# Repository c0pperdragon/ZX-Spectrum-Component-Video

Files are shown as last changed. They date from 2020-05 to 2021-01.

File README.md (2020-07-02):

# ZX-Spectrum-Component-Video
Component video (YPbPr) output for the ZX Spectrum computer 

## General

The ZX Spectrum in its original form produces a radio frequency signal that can be fed into an analog TV. The quality of this
signal is very poor, but this can be improved by a simple modification that will make the ZX Spectrum output a composite video
signal instead. While this is actually better, it is nowhere near good. To bring the video quality to the next level,
this modification will produce a component video signal (YPbPr) that should be as good as an analog signal can possible get.
This video signal can be used either directly with a TV that has a YPbPr input, or it can be passed through a dedicated upscaler device
("Framemeister", "OSSC", etc.) before displaying on an HDMI screen.

This hardware modification is a more compact version of the solution that uses an A-Video board with seperate level shifters.
It tries to solve various shortcomings of https://github.com/c0pperdragon/A-VideoBoard/tree/master/zxspectrummod :

- Smaller and cheaper to make
- No need to modify the case of the ZX Spectrum
- No need to remove any components besides the RF modulator.

## Theory of operation

The mod board passively listens to various digital data lines through which the ULA communicates with the rest of the 
main board - specifically the signals CAS,RW,IOREQ and the data bus. This information is processed by the FPGA 
to figure out what image the ULA intends to display. The FPGA drives a simple 3-channel digital-to-analog converter built from
resistors to produce the 3 output voltages of the YPbPr signal.
Because the main board runs with 5 volt logic levels and the FPGA can only work with 3.3 volts, a voltage regulator and
two input level shifter ICs are necessary (on the bottom side of the mod board). 

## Video output possibilities

- 288p (default) or 576p
- YPbPr (default) or RGsB

Output modes can be selected by jumpers or optional switches.

The color palette I am using has slightly softened colors. The original monochromatic colors are just too hard on
my eyes especially when viewed on a modern display.
I took the platte from [https://lospec.com/palette-list/zx-spectrum] and in my opinion this really looks great.

## Drawbacks

Installation of the mod requires complete removal of the RF modulator. This also implies that an
existing composite video mod will no longer be available. Without further modification the 
ZX Spectrum will then work with component video output exclusively.

If you need composite video additionally you can wire up an extra connector, as the
original analog signals are still being produced by the video output circuit.

## Images
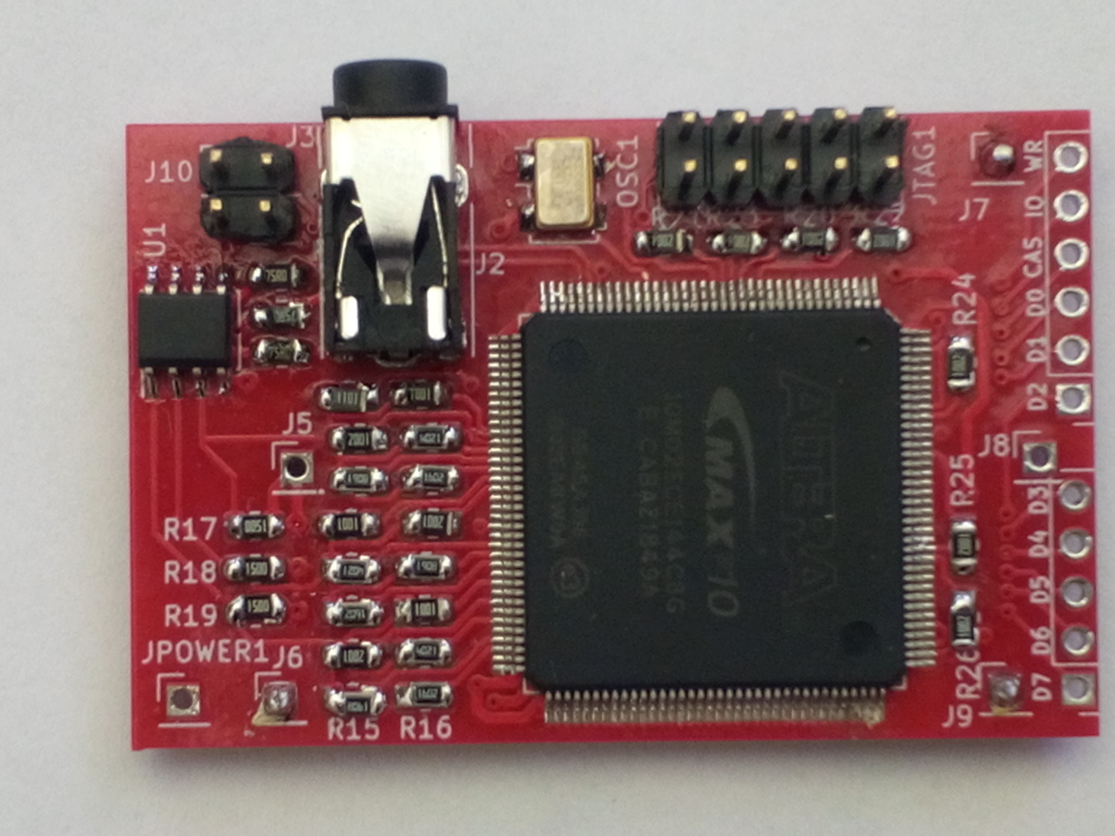
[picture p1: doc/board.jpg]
The mod board itself

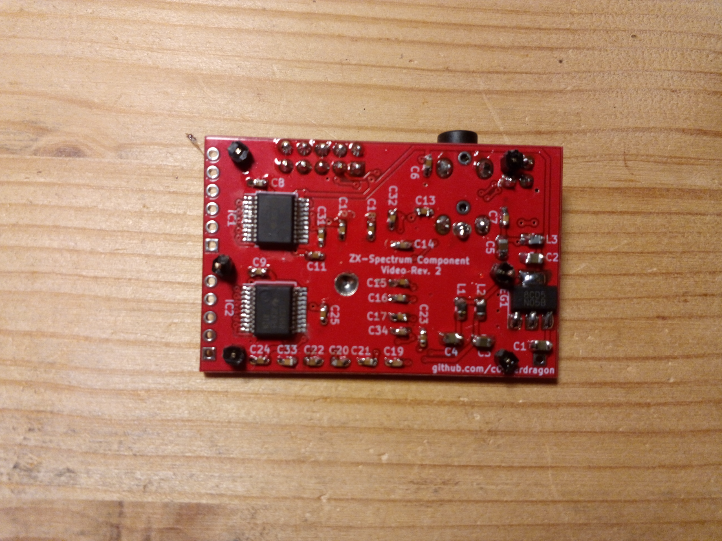
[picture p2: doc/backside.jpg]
Backside

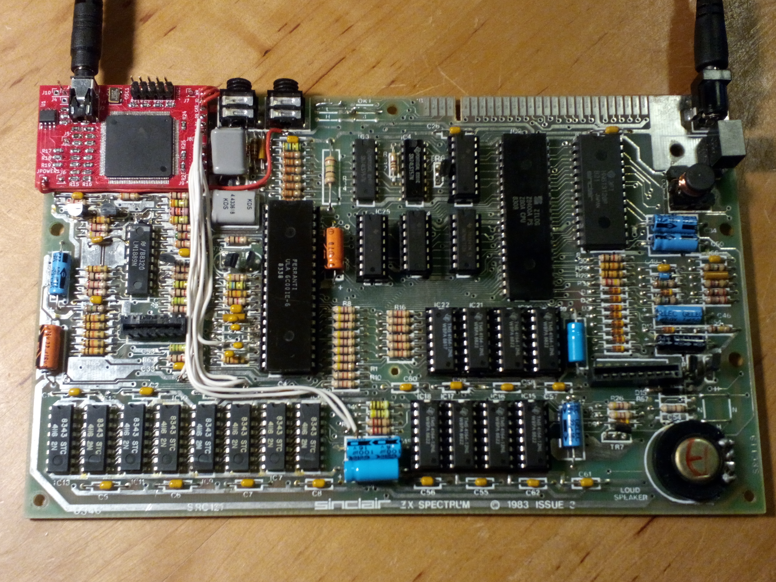
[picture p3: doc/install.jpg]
Installation

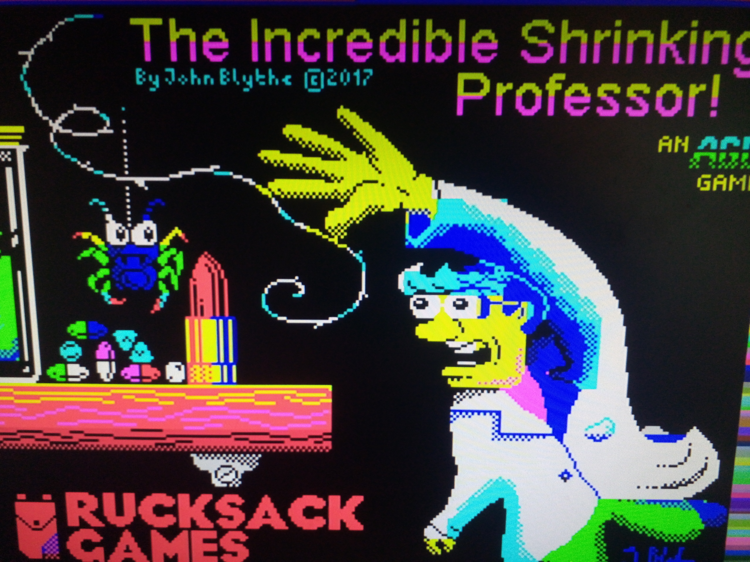
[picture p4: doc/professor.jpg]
Screenshoot

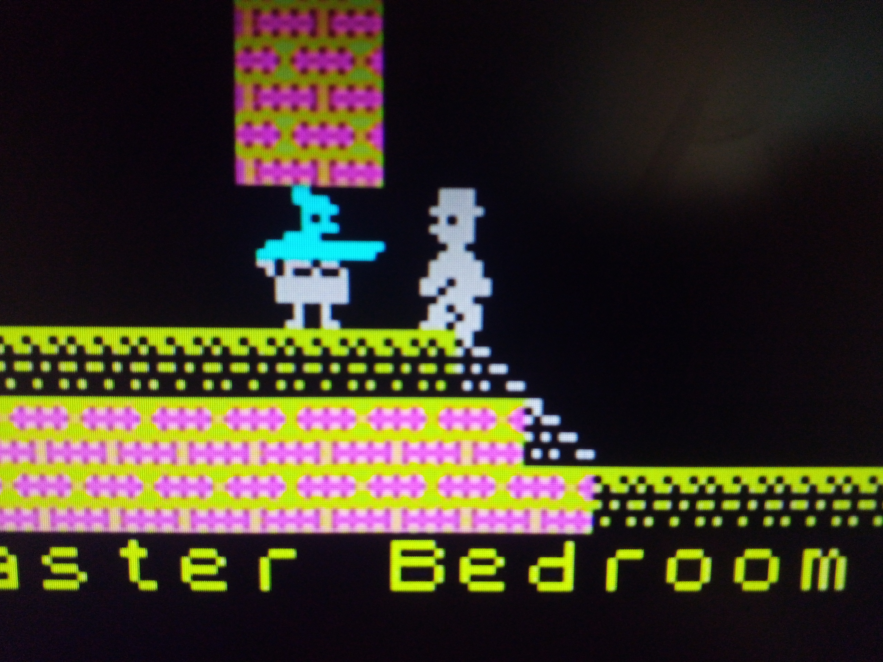
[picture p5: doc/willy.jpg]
Screenshot detail


## Configuration jumpers

You can switch to 576p (enhanced definition TV - double vertical resolution) by bridging the jumper J10.
Likewise you can switch to RGsB output by briding the jumper J3.
Both can either be done with a jumper (permenant setting) or an optional external switch. You can
do that in whatever way you like - maybe there is even a solution that does not require to modify the
case.

## Video adapter cable

The mod uses a small TRRS jack to provide the component video signal. For use with standard cabling,
you will need an adapter to break out the 3 lines to individual RCA jacks. Take care to use a cable
that has the common ground on the sleeve of the tip-ring-ring-sleeve plug.
One possible ready-made product would be: [https://www.delock.de/produkte/S_62499/merkmale.html]

## Installation details

Remove an existing RF modulator completely and remove all the solder from the mounting holes.
Put the mod boad in place of the modulator and solder the two mounting pins. These pins will also
connect the GND levels.
For the following cabling I recommend some single stranded wire that is just thin enough to fit
into the various via holes of the main board. Using via holes wherever possible is the least invasive
option and is also easily reversible.

### Power

+5V power supply must be wired to the JPOWER1 hole of the board. A usable voltage source can be found
for example near the headphone jacks. Do not use the power line that was originally driving the 
RF modulator, as this is comming through some resistor and will not deliver enough current.

### Control signals

The three control signals CAS, IOREQ, WR can best be taken from the backside of the main board directly from
the ULA socket pins (see pin_assignment.txt for more details).

### Data signals

Signals D0 to D7 can be taken from various vias through which the data signals are 
sent on their way between the ULA and the RAM chips. 
The exact locations may differ with board revision. You may have to probe around with a multimeter
to find a conveniently located via for each signal. In the case that you can not 
find any accessible via, you can also solder your wire directly to the RAM chip (but only as last ressort).  

## Assembled boards

I have provided all my assembled boards to videogameperfection.com for sale. 
Please have a look at their website first, and if everything is out of stock, you
can try to contact me directly at at reinhard.grafl (at) aon.at.

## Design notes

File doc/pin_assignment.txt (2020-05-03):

Pin assignments for the ZX-Spectrum-Component-Video mod

ULA sniffing lines
Signal       ULA pin      MAX 10 pin       
WR           2            141
IOREQ        33           140
CAS          1            139
D0           18           138
D1           21           137
D2           22           124
D3           25           123
D4           27           117
D5           29           116
D6           30           114
D7           31           112

Configuration
Function      Jumper        MAX 10 pin   
LINE DOUBLE   J10           31
RGB/YPbPr     J3            32

In-board wiring of the MAX 10 
                         MAX 10 pin
Y(5) = SYNC              46
Y(4)                     47
Y(3)                     48
Y(2)                     49
Y(1)                     50
Y(0)                     51
PB(4)                    52
PB(3)                    53
PB(2)                    59
PB(1)                    60
PB(0)                    61
PR(4)                    63
PR(3)                    65
PR(2)                    67
PR(1)                    69
PR(0)                    70

25Mhz Reference clock:   25

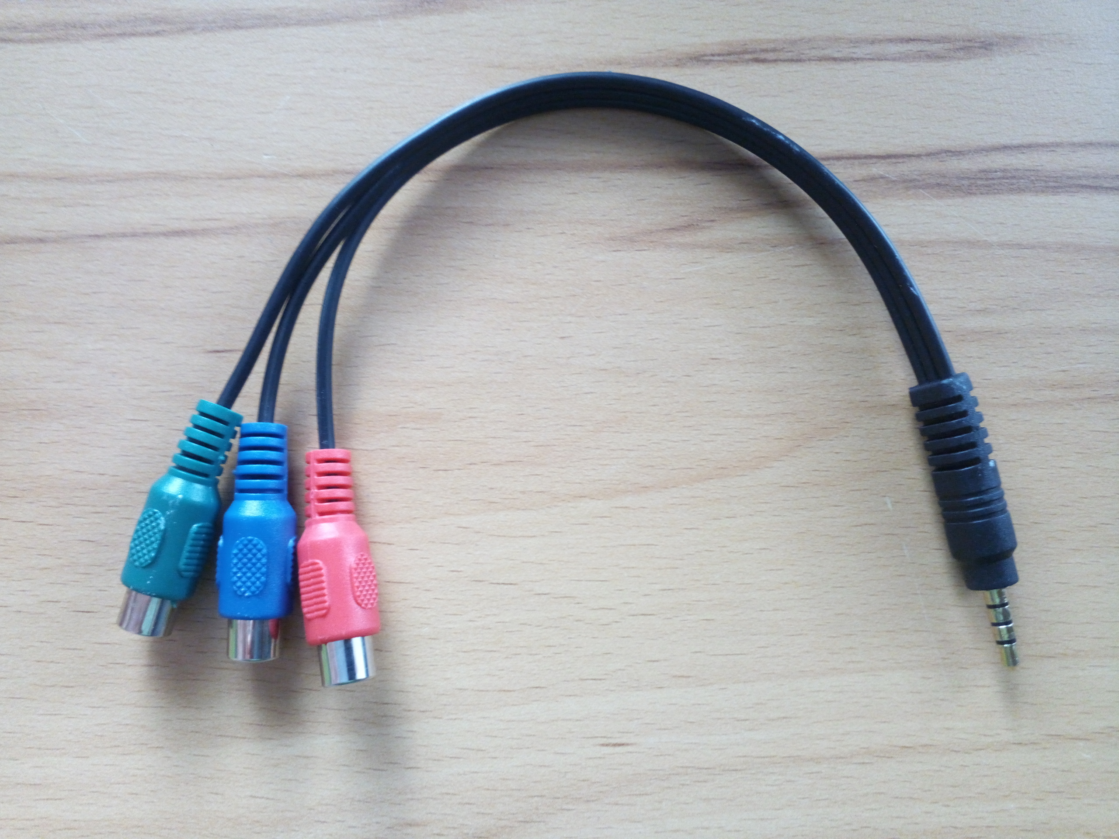
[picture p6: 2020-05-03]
doc/trrsadapter.jpg

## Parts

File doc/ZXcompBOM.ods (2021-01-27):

Manufacturer | Manufacturer Number | Designator | Qty | Description | Case | SMD/ TH | PCB side | Comments
Intel | 10M02SCE144C8G | U2 | 1 | FPGA - Field Programmable Gate Array, | 144EQFP | SMD | Top | When hand-soldering: Solder center pad from bottom side
Texas Instruments | THS7316DR | U1 | 1 | Video Amplifiers 3-Ch HDTV Video Amp | SOIC-8 | SMD | Top
Texas Instruments | LM1117IMPX-3.3/NOPB | REG1 | 1 | LDO Voltage Regulators 800MA LDO LINEAR REG | SOT-223-4 | SMD | Bot
IQD Frequency Products | LFSPXO024957Reel | OSC1 | 1 | Standard Clock Oscillators 25MHz 3.3V 50ppm -40C +85C | 5 mm x 3.2 mm | SMD | Top
Cliff | FC68125 | J2 | 1 | TRRS Jack |  | TH | Top
Texas Instruments | LVC245A | IC1,IC2 | 2 | 3.3V Octal Bus Transceivers | TSSOP-20 | SMD | Bot
any |  | L1,L2,L3 | 3 | Fixed inductors 10uH, 20% | 2012 | SMD | Bot
any |  | C1,C2,C3,C4,C5 | 5 | Ceramic capacitor 10uF, 16V, 20% | 2012 | SMD | Bot
any |  | C6-C9,C11-C34 | 23 | Ceramic capacitor 100nF, 16V, 20% | 1608 | SMD | Bot
any |  | R1 | 1 | Thick film resistor, 1.1k Ohm, 1% | 2012 | SMD | Top
any |  | R27,R28,R29 | 3 | Thick film resistor, 75 Ohm, 1% | 2012 | SMD | Top
any |  | R17,R18,R19 | 3 | Thick film resistor, 150 Ohm, 1% | 2012 | SMD | Top
any |  | R2,R7,R12 | 3 | Thick film resistor, 1k Ohm, 1% | 2012 | SMD | Top
any |  | R3,R8,R13 | 3 | Thick film resistor, 2k Ohm, 1% | 2012 | SMD | Top
any |  | R4,R9,R14 | 3 | Thick film resistor, 4.02k Ohm, 1% | 2012 | SMD | Top
any |  | R5,R10,R15 | 3 | Thick film resistor, 8.06k Ohm, 1% | 2012 | SMD | Top
any |  | R6,R11,R16 | 3 | Thick film resistor, 16k Ohm, 1% | 2012 | SMD | Top
any |  | R20-R26 | 7 | Thick film resistor, 10k Ohm, 1% | 2012 | SMD | Top
any |  | JTAG1 | 1 | Standard pin header, 2x5 pins, 2.54mm, gold plated |  | TH | Top
any |  | J3,J10 | 2 | Standard pin header, 1x2 pins, 2.54mm, gold plated |  | TH | Top
any |  | J5,J6,J7,J8,J9 | 5 | Standard pin header, 1 pin, gold plated |  | TH | Bot

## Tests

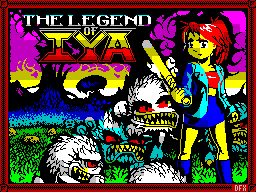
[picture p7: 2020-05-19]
testcircuit/testimage.png

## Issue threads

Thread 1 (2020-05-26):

Feedback and experiences

c0pperdragon, 2020-05-26:
Please let the community know about your experiences with the mod. Photographs and screenshots would be highly appreciated.
For troubleshooting and specific detail questions, please create individual issue threads.

IanSB, 2022-04-25:
@c0pperdragon

I finally fitted this board to my 48K Spectrum and it works OK with RGBtoHDMI (In RGsB mode)
I have created a profile (attached) but there is a problem: The border is too narrow
Here is a screencap from your interface:

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

Here is a screencap from the analog YUV on the Spectrum edge connector (no bright colours):

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

Here is the profile I am using for my tests:
[Spectrum_48K+c0pperDragon.txt](https://github.com/c0pperdragon/ZX-Spectrum-Component-Video/files/8558426/Spectrum_48K%2Bc0pperDragon.txt)

IanSB, 2022-04-26:
@c0pperdragon
Looking at the video signal, the original Spectrum source is approximately 352 pixels wide and 288 pixels high so the border really needs to be around that size to ensure that the video is captured properly in all circumstances.

c0pperdragon, 2022-04-28:
I have released a new firmware (1.1) for the zx spectrum mod.
For programming this with the USB-Blaster, make sure that the cable as the correct orientation on the JTAG header. Pin 1 is on the side nearer the video jack.

IanSB, 2022-04-30:
@c0pperdragon

Thanks, that seems to work OK

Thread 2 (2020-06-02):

Adding a CAS wire to the  EDGE connector instead of removing RF modulator ?

amidarius, 2020-06-02:
Please correct me if i'm wrong but,
simple modificiation, adding a wire from CAS/Write (If this is ULA -> 4116 write? ) "test points" to the unused/NC pins on the EDGE connector (Component side 4/28) and You do not need to remove RF modulator anymore from the Spectrum. All other signals are already there, so this could be just an another expansion card to the ZX Spectrum 16/48K !
Data bus is already shared between 4116 an the rest of the computer so it is already available at the EDGE connector.

c0pperdragon, 2020-06-02:
Indeed, I have to correct you. This machine actually has two seperate data bussses that are coupled together with resistors. As long as the CPU does not need to access the video RAM, it can work with its dedicated RAM and ROM independently of the ULA. Only when accessing the video RAM, the ULA forwards this requests to its own part of the system, or blocks the CPU altogether until it is done with RAM access itself.

The pins that are accessible on the edge connector carry the CPUs addresses and data. The data that is pulled by the ULA from the video RAM normally does not reach the CPU bus at all and in consequence  can not be sniffed from the edge connector.

amidarius, 2020-06-03:
Yes, that's the way it works.
Just consulted ZX Spectrum 48K Issue 2 schematic and Chris Smith's ULA Bible, 'The Spectrum ULA - How to Design A Microcomputer' and everything is crystal clear again, after 35 years ! :-)
It seems that 'socketed ULA' :-) if it's somehow there, the easiest solution if You do not want to remove RF modulator. My Spectrum is already inside very big mechanical keyboard, so, space is not a problem and the solution is reversible with additional simple PCB.
Anyway, is it possible to connect this board without removing RF modulator when, like in my case, space is not a problem ? It should be.

Closed 2020-09-11.

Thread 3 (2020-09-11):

RGBtoHDMI profile

IanSB, 2020-09-11:
What are the default YUV levels for the ouput of this mod?

c0pperdragon, 2020-09-11:
YPbPr is not well suited to work with the RGBtoHDMI because the Ys are too close together. Set jumper J3 to get RGsB output. There all color components are either 0, 1 or 0.5 (not quite, but close enough)

IanSB, 2020-09-11:
I wonder if it would be possible to implement the functionality of this mod in the RGBtoHDMI CPLD (or a combination of the CPLD and software) as there are now 14 bits available on the CPLD inputs (12 RGB + HS & VS) which is more than enough to pick up the required signals, especially if it could be connected externally as suggested in https://github.com/c0pperdragon/ZX-Spectrum-Component-Video/issues/2

c0pperdragon, 2020-09-11:
Unluckily the data signals by which the ULA communicates with the video RAM are _not_ available on the  edge connector (please see my reply to this topic).
The only way to do something similar via the edge connector is to sniff all address and data bits and memorize what the CPU writes into the video RAM. Could be possible, but requires far more signals.
Also the edge connector is in so much use for other purposes already.

IanSB, 2020-09-11:
>The only way to do something similar via the edge connector is to sniff all address and data bits and memorize what the CPU writes into the video RAM. Could be possible, but requires far more signals.

Yes, I think there are a couple of other solutions that work that way, one of which also uses a CPLD and a Pi zero.

Still, it might be worth investigating an internal pickup solution like my current Atari / Amiga options. I think the CPLD would only be able to latch the data bus and control bits at the appropriate time and pass them to the Pi for a purely software emulation of the Spectrum's colour attribute based frame buffer. Something to look at one day.

Have you tried creating a profile for your Spectrum board yet?

c0pperdragon, 2020-09-12:
I didn't put any attention on the Spectrum yet  I basically hoped, you would take care of that 😉

Going digital directly is of course also an option. Maybe the space inside the original Speccy is a bit too restricted. Using a CPLD you could directly replace the whole ULA and produce a 4-bit video signal like later versions of the Spectrum did. This could then allow a unified RGBtoHDMI solution.

patters-syno, 2021-03-02:
Is it possible to take your design a little further and actually output HDMI (via a micro HDMI connector, which would also avoid modding the case)? The issue these days is that the latest TVs don't even have component inputs. Having spent the "lockdown" period researching and buying various HDMI solutions for my various retro consoles, the Spectrum is still a system I can only use on an older TV.

IanSB, 2022-04-30:
Profile now available in beta 54 of RGBtoHDMI

Closed 2022-04-30.

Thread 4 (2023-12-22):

Edge connector

kladogen, 2023-12-22:
I'm thinking about building a board that connects to the edge connector and get the signals from there. The only required signal that I did not see on the edge connector is CAS, but I think it better to have just one cable. Would you think it is possible?

c0pperdragon, 2023-12-22:
I guess if you have the CPU clock signal as well as the Y (luminance & sync), you may very well be able to sync your implementation to the inner workings of the ULA. With all the other signals available as well, this should actually work.

Maybe you consider creating a Lumacode signal as well as RGB, so it could also be integrated in my new  Lumacode infrastructure.

kladogen, 2023-12-22:
Hi, also I was just reading the ZX Spectrum Service Manual that mentions "The RAS/CAS outputs from the ULA are generated in sequence in response to MREQ and A14 from the CPU.". Do you think it is possible for the FPGA to use theese signals instead of CAS and therefore the board could become an extension of the Spectrum on the Edge Connector? Probably it needs some work to define with a logic analyser to define exactly how CAS is produced from MREQ and A14 but its only 4 combinations.

c0pperdragon, 2023-12-22:
It is actually much more involved than that. The ULA does create the CAS/RAS signals in behalf of the CPU when it wants to access the low RAM, but it also does such accesses on its own to get the video data. Even worse, when there is a conflict between CPU access and ULA access, the ULA stops the CPU clock until it is finished itself. So just using the CPU clock directly to drive the logic will not work without some means to bridge the time when no clock is generated.
All this is pretty difficult and needs some serious FPGA wizardry which is no project for  the faint of heart. Maybe I will try it myself.

c0pperdragon, 2023-12-23:
Thought about the idea with the edge connector a bit more, and I was basically mistaken here. It is not possible to sniff all the ULA data traffic on the edge connector because the ZX Spectrum has a split data bus of which only the CPU side of things is available on the edge connector. In the cases where the CPU executes code from the uncontested memory, the ULA can do its own thing completely independently and nothing of this will show up on the external data lines.

Only thing that may actually work would be to sniff the CPU write accesses to the video RAM and keep your own copy of this data and genereate the video from this. But this would be a completely different approach.

kladogen, 2023-12-23:
That was my initial intention when I found your project. I was thinking of a project using a raspberry pico to monitor the address bus and data bus, store any writes into it's own RAM and from there produce a VGA output. However, since the IO pins of the pico are not enough to both monitor the IO and produce the VGA output, probably a Parallel to Serial register would be needed for the data bus. This could be done using raspberry pico PIO to get the data fast in the memory and then create the output picture according to the memory contents. That would work like an external graphics card. However, I'm not sure about the border - I don't think the data for that is in the Spectrum's graphics RAM, rather it is produced by the ULA according to other instructions maybe OUTs. Probably these could also be monitored but it would if someone knew what to look for.

c0pperdragon, 2023-12-23:
Yes, the border color is not taken from RAM, but from the internal registers of the ULA. This is written by the CPU with an OUT instruction.

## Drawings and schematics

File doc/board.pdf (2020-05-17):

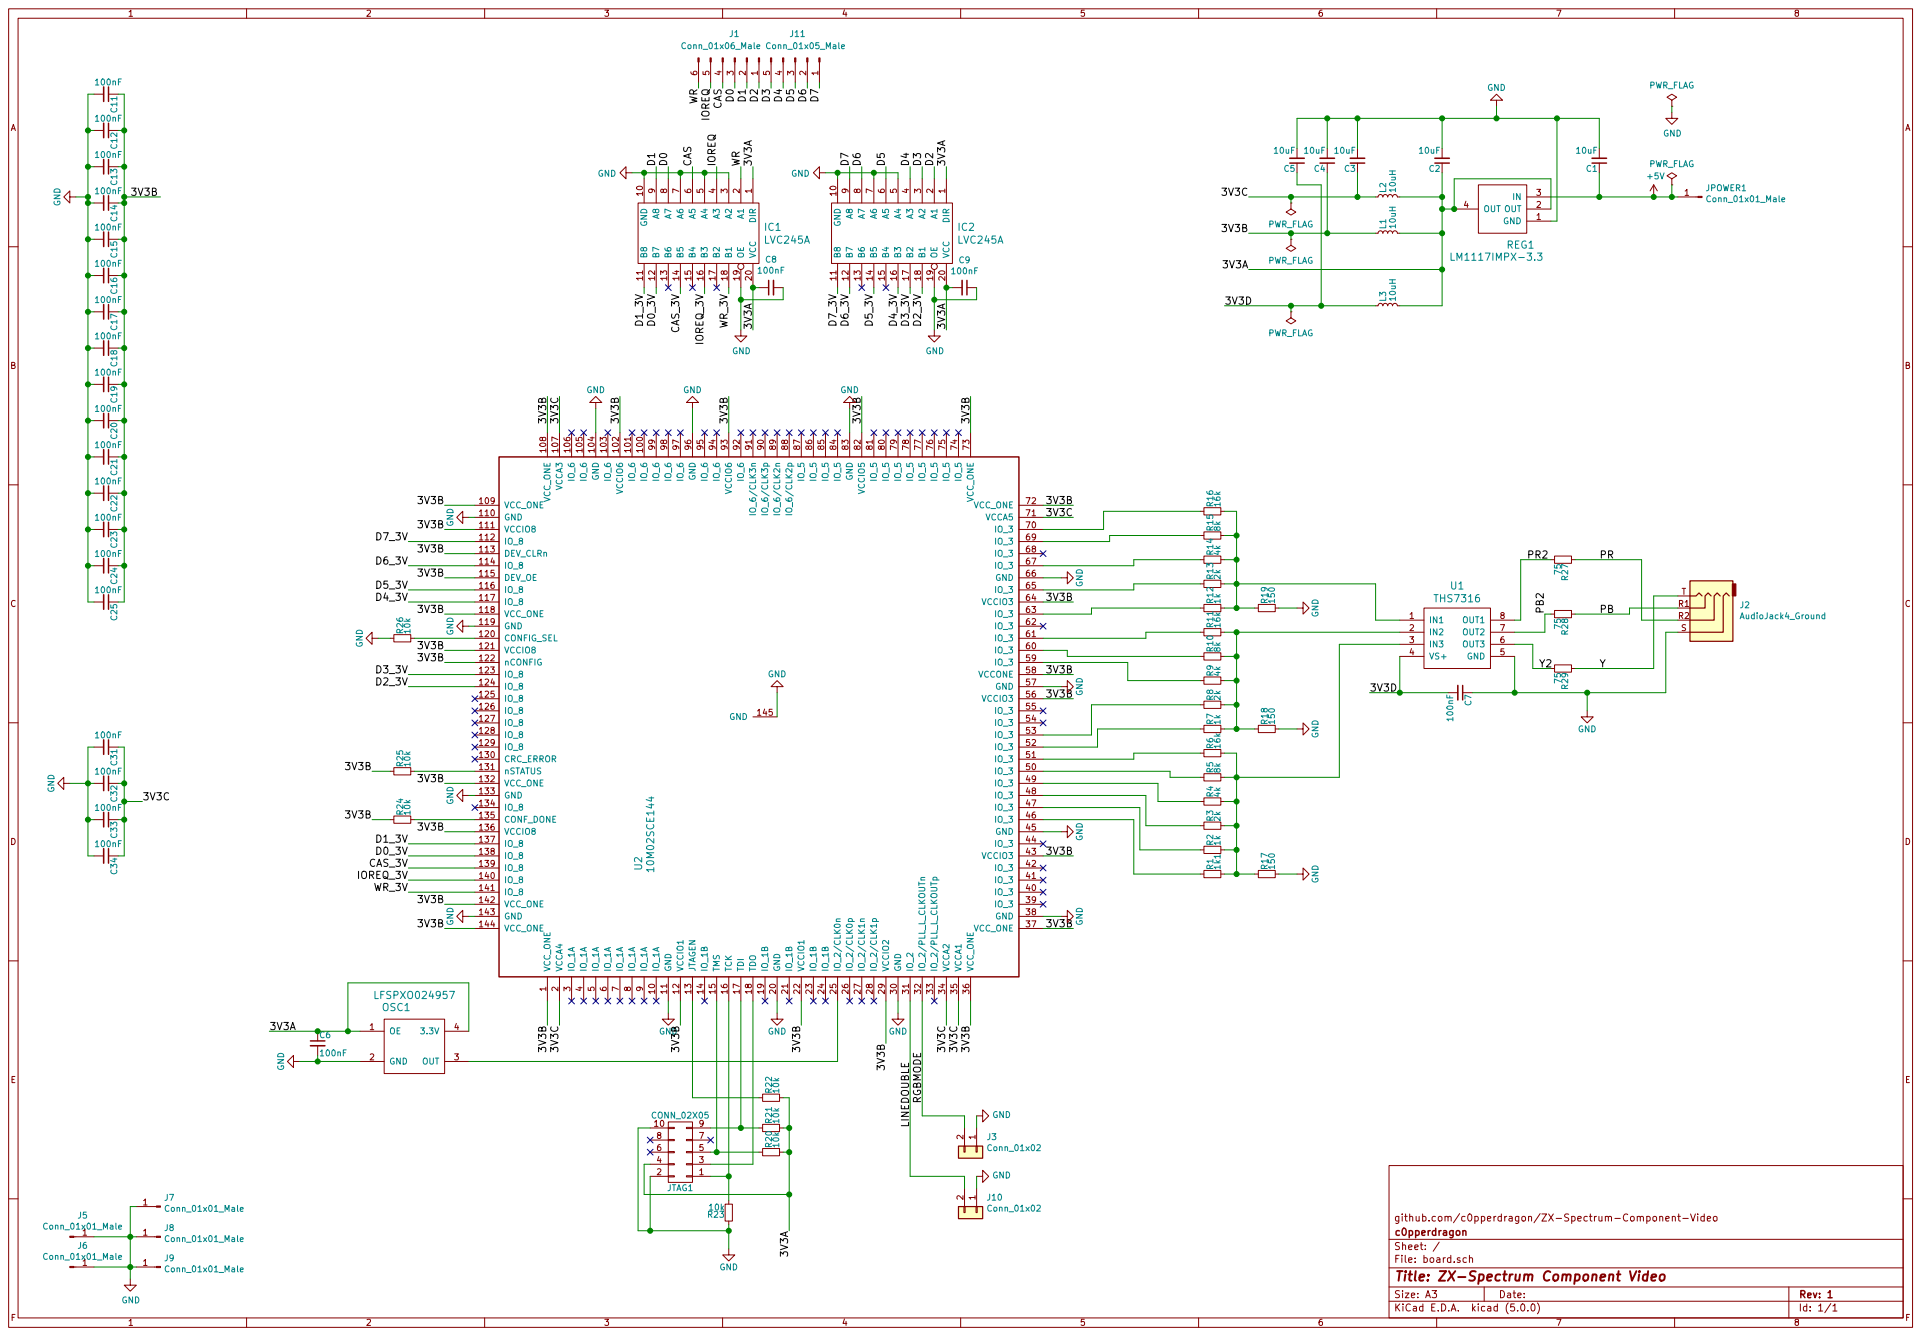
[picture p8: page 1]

github.com/c0pperdragon/ZX-Spectrum-Component-Video GND

File: board.sch Sheet: / c0pperdragon

Id: 1/1 Title: ZX-Spectrum Component Video

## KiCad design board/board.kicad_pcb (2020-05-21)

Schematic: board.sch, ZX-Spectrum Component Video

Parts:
C1, C2, C3, C4, C5: 10uF; C_0805_2012Metric_Pad1.15x1.40mm_HandSolder
C6, C7, C8, C9, C11, C12, C13, C14, C15, C16, C17, C18, C19, C20, C21, C22, C23, C24, C25, C31, C32, C33, C34: 100nF; C_0603_1608Metric_Pad1.05x0.95mm_HandSolder
IC1, IC2: LVC245A; SSOP-20_5.3x7.2mm_P0.65mm
J1: Conn_01x06_Male; PinHeader_1x06_P2.54mm_Vertical
J2: AudioJack4_Ground; Conrad 4pin audio jack
J3, J10: Conn_01x02; PinHeader_2x01_P2.54mm_Vertical
J5, J6, J7, J8, J9: Conn_01x01_Male; PinHeader_1x01_P2.54mm_Vertical
J11: Conn_01x05_Male; PinHeader_1x05_P2.54mm_Vertical
JPOWER1: Conn_01x01_Male; PinHeader_1x01_P2.54mm_Vertical
JTAG1: CONN_02X05; PinHeader_2x05_P2.54mm_Vertical
L1, L2, L3: 10uH; C_0805_2012Metric_Pad1.15x1.40mm_HandSolder
OSC1: LFSPXO024957; Oscillator_SMD_EuroQuartz_XO53-4Pin_5.0x3.2mm_HandSoldering
R1: 1k1; R_0805_2012Metric_Pad1.15x1.40mm_HandSolder
R2, R7, R12: 1k; R_0805_2012Metric_Pad1.15x1.40mm_HandSolder
R3, R8, R13: 2k; R_0805_2012Metric_Pad1.15x1.40mm_HandSolder
R4, R9, R14: 4k; R_0805_2012Metric_Pad1.15x1.40mm_HandSolder
R5, R10, R15: 8k; R_0805_2012Metric_Pad1.15x1.40mm_HandSolder
R6, R11, R16: 16k; R_0805_2012Metric_Pad1.15x1.40mm_HandSolder
R17, R18, R19: 150; R_0805_2012Metric_Pad1.15x1.40mm_HandSolder
R20, R21, R22, R23, R24, R25, R26: 10k; R_0805_2012Metric_Pad1.15x1.40mm_HandSolder
R27, R28, R29: 75; R_0805_2012Metric_Pad1.15x1.40mm_HandSolder
REG1: LM1117IMPX-3.3; SOT-223
U1: THS7316; SOIC-8_3.9x4.9mm_P1.27mm
U2: 10M02SCE144; QFP_144_GND

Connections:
+5V: C1.1, JPOWER1.1, REG1.3
/3V3A: C2.1, C6.1, C8.1, C9.2, IC1.1, IC1.20, IC2.1, IC2.20, JTAG1.4, L1.2, L2.2, L3.2, OSC1.1, OSC1.4, R20.2, R21.2, R22.2, REG1.2, REG1.4
/3V3B: C4.1, C11.1, C12.1, C13.1, C14.1, C15.1, C16.1, C17.1, C18.1, C19.1, C20.1, C21.1, C22.1, C23.1, C24.1, C25.1, L1.1, R24.1, R25.1, U2.1, U2.12, U2.22, U2.29, U2.36, U2.37, U2.43, U2.56, U2.58, U2.64, U2.72, U2.73, U2.82, U2.93, U2.102, U2.108, U2.109, U2.111, U2.113, U2.115, U2.118, U2.121, U2.122, U2.132, U2.136, U2.142, U2.144
/3V3C: C3.1, C31.1, C32.1, C33.1, C34.1, L2.1, U2.2, U2.34, U2.35, U2.71, U2.107
/3V3D: C5.1, C7.2, L3.1, U1.4
/CAS: IC1.6, J1.4
/CAS_3V: IC1.14, U2.139
/D0: IC1.8, J1.3
/D0_3V: IC1.12, U2.138
/D1: IC1.9, J1.2
/D1_3V: IC1.11, U2.137
/D2: IC2.2, J1.1
/D2_3V: IC2.18, U2.124
/D3: IC2.3, J11.5
/D3_3V: IC2.17, U2.123
/D4: IC2.4, J11.4
/D4_3V: IC2.16, U2.117
/D5: IC2.6, J11.3
/D5_3V: IC2.14, U2.116
/D6: IC2.8, J11.2
/D6_3V: IC2.12, U2.114
/D7: IC2.9, J11.1
/D7_3V: IC2.11, U2.112
/IOREQ: IC1.4, J1.5
/IOREQ_3V: IC1.16, U2.140
/LINEDOUBLE: J10.2, U2.31
/PB: J2.R1, R28.1
/PB2: R28.2, U1.7
/PR: J2.R2, R27.1
/PR2: R27.2, U1.8
/RGBMODE: J3.2, U2.32
/WR: IC1.2, J1.6
/WR_3V: IC1.18, U2.141
/Y: J2.T, R29.1
/Y2: R29.2, U1.6
GND: C1.2, C2.2, C3.2, C4.2, C5.2, C6.2, C7.1, C8.2, C9.1, C11.2, C12.2, C13.2, C14.2, C15.2, C16.2, C17.2, C18.2, C19.2, C20.2, C21.2, C22.2, C23.2, C24.2, C25.2, C31.2, C32.2, C33.2, C34.2, IC1.3, IC1.5, IC1.7, IC1.10, IC1.19, IC2.5, IC2.7, IC2.10, IC2.19, J2.S, J3.1, J5.1, J6.1, J7.1, J8.1, J9.1, J10.1, JTAG1.2, JTAG1.10, OSC1.2, R17.2, R18.2, R19.2, R23.1, R26.1, REG1.1, U1.5, U2.11, U2.20, U2.30, U2.38, U2.45, U2.57, U2.66, U2.83, U2.96, U2.104, U2.110, U2.119, U2.133, U2.143, U2.145
unnamed: JTAG1.1, R23.2, U2.16
unnamed: JTAG1.3, U2.18
unnamed: JTAG1.5, R20.1, U2.15
unnamed: JTAG1.9, R21.1, U2.17
unnamed: OSC1.3, U2.25
unnamed: R1.1, U2.46
unnamed: R1.2, R2.2, R3.2, R4.2, R5.2, R6.2, R17.1, U1.3
unnamed: R2.1, U2.47
unnamed: R3.1, U2.48
unnamed: R4.1, U2.49
unnamed: R5.1, U2.50
unnamed: R6.1, U2.51
unnamed: R7.1, U2.52
unnamed: R8.1, U2.53
unnamed: R9.1, U2.59
unnamed: R10.1, U2.60
unnamed: R7.2, R8.2, R9.2, R10.2, R11.2, R18.1, U1.2
unnamed: R11.1, U2.61
unnamed: R12.1, U2.63
unnamed: R12.2, R13.2, R14.2, R15.2, R16.2, R19.1, U1.1
unnamed: R13.1, U2.65
unnamed: R14.1, U2.67
unnamed: R15.1, U2.69
unnamed: R16.1, U2.70
unnamed: R22.1, U2.13
unnamed: R24.2, U2.135
unnamed: R25.2, U2.131
unnamed: R26.2, U2.120

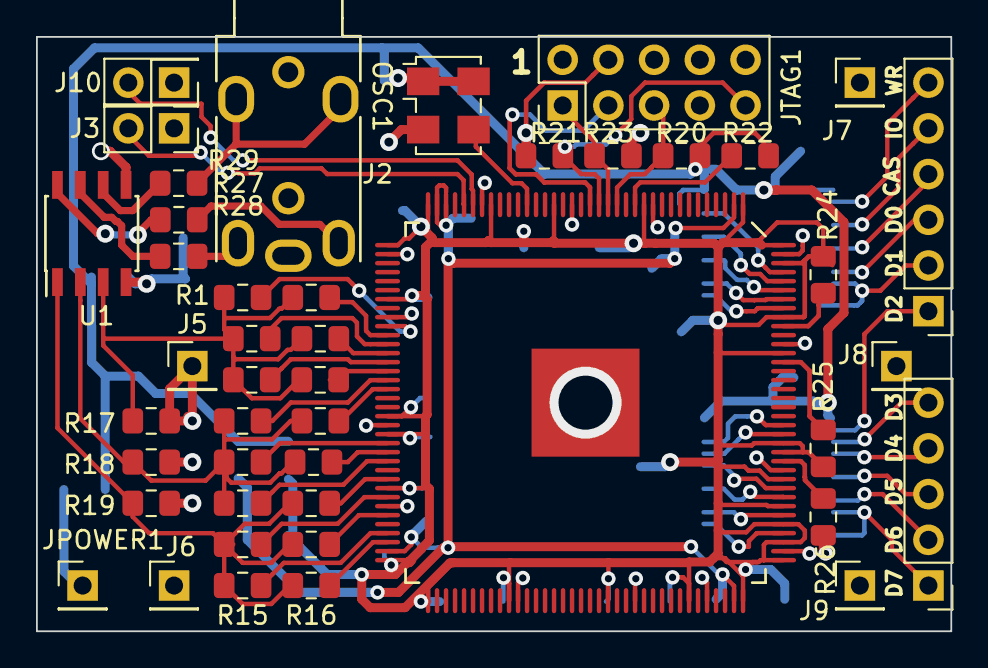
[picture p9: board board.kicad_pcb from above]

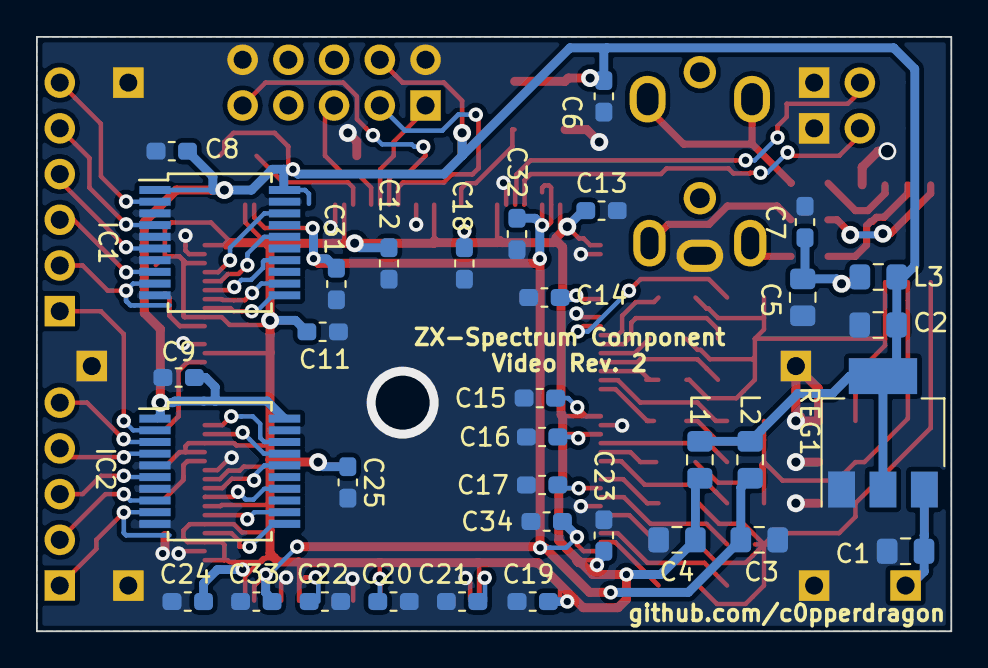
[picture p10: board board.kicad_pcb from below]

Board: 2 copper layers, 50.8 x 33.0 mm, 78 parts (34 on the bottom side), 64 nets.

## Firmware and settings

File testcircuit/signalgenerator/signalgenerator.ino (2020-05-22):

// Test signal generator for a ZX Spectrum component video mod board.
// This program is designed to run on an Arduino Uno to drive the various
// input signals of the mod board.

// Wiring up the signal pins: 
//    Arduino           Mod board
//    pin 0 - pin 7     D0 - D7
//    pin A3            CAS
//    pin A4            IOREQ
//    pin A5            WR


static const byte PROGMEM attributes[32*24] = 
{
    B00000010,B00000010,B00000010,B00000010,B00000010,B00000010,B00000010,B00000010,B00000010,B00000010,B00000010,B00000010,B00000010,B00000010,B00000010,B00000010,B00000010,B00000010,B00000010,B00000010,B00000010,B00000010,B00000010,B00000010,B00000010,B00000010,B00000010,B00000010,B00000010,B00000010,B00000010,B00000010,
    B00000010,B01000011,B01000011,B01000101,B01000101,B01000101,B01000101,B01000101,B01000101,B01000101,B01000101,B01000101,B01000101,B01000101,B01000101,B01000101,B00000000,B01000101,B01000101,B00000000,B01000011,B01000011,B01000011,B01000011,B01000011,B01000011,B00000000,B01000011,B01000011,B01000011,B01000011,B00000010,
    B00000010,B01000011,B01000011,B01000111,B01000111,B01000111,B01000111,B01000111,B01000111,B01000111,B01000111,B01000111,B01000111,B01000111,B01000111,B01000111,B01000111,B01000111,B01000111,B00000011,B00000011,B00000011,B00000010,B00000010,B01000010,B00000000,B00000010,B00000010,B01000011,B01011011,B01000011,B00000010,
    B00000010,B00000011,B01000011,B00000111,B01000011,B00000111,B00000111,B00000111,B00000111,B00000111,B00000111,B00000111,B00000111,B00000111,B00000111,B00000111,B00000111,B00000111,B00000011,B00000011,B00000011,B00000011,B00000010,B00000010,B00000010,B01010111,B01010111,B01000010,B01000010,B00000011,B01000011,B00000010,
    B00000010,B00000011,B00000011,B01000011,B01000011,B01000110,B01000110,B01000110,B01000110,B01000110,B01000110,B01000110,B01000110,B01000110,B01000110,B01000110,B01000110,B00000000,B01000011,B00000011,B00000011,B00000011,B00000010,B00000110,B00000110,B01010110,B01000010,B01000010,B00000010,B00000011,B00000011,B00000010,
    B00000010,B00000011,B00011011,B00011011,B00000011,B00000011,B00000110,B00000110,B00000011,B00000110,B00000110,B00000110,B00000110,B00000110,B00000110,B00000110,B01000110,B00000111,B00000111,B00000110,B00000011,B00000011,B00000010,B00000111,B01000110,B01000111,B01010110,B01000010,B00000010,B00000011,B00000011,B00000010,
    B00000010,B00000011,B00011011,B00011011,B00000011,B01000010,B01000010,B01000010,B01000010,B00000011,B01000010,B01000010,B01000010,B01000010,B01000010,B01000010,B01000010,B00000000,B00000110,B00000110,B00000011,B00000011,B00000011,B00000110,B00000110,B01000110,B01000110,B01000010,B00000010,B00000011,B00000011,B00000010,
    B00000010,B00000011,B00011110,B00011110,B00000011,B00000010,B00000010,B00000010,B00000010,B00000010,B00000010,B00000010,B00000010,B00000010,B00000010,B00000010,B00000010,B00000000,B00000110,B01000110,B01000110,B01000111,B00000000,B00000101,B00000110,B01000110,B01000110,B01000010,B00000010,B00000011,B00000011,B00000010,
    B00000010,B00000011,B00011110,B00011110,B00011110,B00000011,B00000011,B00000011,B00000011,B00011110,B00011110,B00011110,B00011110,B00011110,B00011110,B00011110,B00000011,B00000000,B01000111,B01110111,B01000110,B01000111,B01000111,B00000001,B01000101,B01101110,B01000110,B01000101,B00000011,B00000011,B00000011,B00000010,
    B00000010,B00000110,B00110110,B00011110,B00011110,B00000110,B00000000,B00000110,B00000110,B00110110,B00000110,B00000110,B00000110,B00000110,B00011110,B00000110,B01000110,B00000111,B00000111,B01000111,B01000110,B01000110,B00000001,B00001101,B00000101,B01010101,B01010111,B01010101,B00000110,B00000110,B00000110,B00000010,
    B00000010,B01000110,B01000110,B01000110,B01000110,B00000001,B00000001,B01000110,B01110110,B01000110,B00000001,B00000001,B00000001,B01000110,B01000110,B01000110,B00000111,B00000111,B01000111,B01000111,B00000111,B01000110,B00000001,B00001101,B00000001,B01000101,B01000010,B01010101,B01000110,B01110110,B01000110,B00000010,
    B00000010,B00000000,B00000011,B01000111,B01000111,B00000001,B00000001,B00000001,B01000111,B01000111,B01000111,B01000111,B01000111,B01000111,B01000111,B00000111,B00000111,B01000111,B01111111,B01000111,B01000111,B00000110,B01000110,B00001101,B00000001,B01000101,B01000110,B01000101,B01000111,B01000111,B01000111,B00000010,
    B00000010,B00000000,B00000000,B00000000,B00000001,B00000001,B00000001,B00000001,B01000111,B01000111,B01000111,B01000001,B00000001,B01000001,B01000111,B01000111,B00000111,B01000111,B01000111,B01000111,B01000010,B00000110,B01000110,B01000110,B00000000,B01000101,B01000001,B01000101,B01000101,B00000111,B00000111,B00000010,
    B00000010,B00000001,B00000001,B00000001,B00000001,B00000001,B00000001,B00000001,B00000001,B00000001,B00000001,B00000001,B00000001,B00000101,B01000111,B01000111,B00000111,B01000010,B01000010,B01010111,B01010111,B01000111,B00000001,B00000101,B00000101,B01000101,B01001001,B01000001,B01000101,B01000101,B00000101,B00000010,
    B00000010,B00001101,B00001101,B00001101,B00001101,B00001101,B00001101,B00001101,B00001101,B00001101,B00001111,B00001111,B00001101,B01000111,B00000111,B00000111,B00000111,B00000110,B00000110,B01000110,B00000110,B00000110,B00000111,B00000001,B00000101,B01001101,B01001001,B01000001,B00000101,B01000110,B00000101,B00000010,
    B00000010,B00000101,B00000101,B00000101,B00000101,B00000101,B00000101,B00000101,B00000101,B00000101,B00000101,B00000101,B01000101,B01000111,B00000111,B00000101,B00000111,B01000111,B01000110,B01000110,B01000110,B00000110,B00000111,B00000001,B00000001,B00000001,B01000001,B01001110,B00000110,B00000110,B00000010,B00000010,
    B00000010,B00000110,B00000100,B00000100,B00000100,B00000100,B00000110,B00000100,B00000100,B00000101,B00000101,B00000101,B01000101,B01000101,B01000101,B00000101,B00000111,B00000111,B01000111,B01000111,B01000111,B01000111,B00000110,B01000110,B01000110,B00000101,B00000110,B01110110,B01000110,B00000110,B00000110,B00000010,
    B00000010,B00000100,B00000100,B00000110,B00000110,B00000100,B01000100,B01000111,B01000111,B01000111,B01000111,B01000111,B00000101,B01000010,B00000010,B00000101,B00000010,B01000010,B00000101,B00000111,B00000111,B00000111,B00000110,B01000110,B01000110,B00000101,B00000110,B01000110,B01000110,B00000110,B00000110,B00000010,
    B00000010,B01000100,B00000100,B00000100,B00000100,B00000100,B00000111,B01000111,B01000111,B01000111,B01000111,B01000111,B00000101,B00000101,B00000110,B01000110,B01000110,B00000110,B00000101,B00000101,B00000101,B00000100,B00000110,B01000110,B01000110,B00000000,B00000101,B01000110,B01000110,B00000101,B00000101,B00000010,
    B00000010,B00000100,B01000100,B00000100,B01000100,B00000100,B00000111,B01000111,B01000111,B01000111,B01000111,B01000111,B01000111,B00000101,B00000101,B00000101,B00000101,B00000110,B00000101,B00000101,B00000101,B00000100,B01000110,B01000110,B00000100,B00000101,B00000101,B01000110,B01000110,B00000100,B00000100,B00000010,
    B00000010,B01000100,B00000100,B01000100,B00000100,B00000111,B00000111,B00000111,B01000111,B01000111,B00000111,B01000010,B00000111,B00000100,B00000100,B00000101,B00000101,B00000101,B00000111,B01000111,B01000111,B00000111,B00000001,B01000001,B00000100,B00000110,B00000110,B00000001,B01000001,B00000100,B00000100,B00000010,
    B00000010,B01000100,B01000100,B01000100,B01000100,B00000000,B00000111,B00000111,B00000111,B01000110,B01000110,B01000111,B01000111,B00000100,B01000100,B01000100,B00000111,B00000111,B01000111,B01000111,B01000111,B01000111,B00000111,B01000001,B01000100,B01000100,B01000100,B00000001,B01000001,B01000100,B01000100,B00000010,
    B00000010,B01000100,B01000100,B01000100,B00000111,B01000111,B00000111,B01000111,B01000111,B01000111,B01000110,B00000111,B01000111,B01000100,B01000100,B01000100,B00000111,B01000111,B01000111,B01000111,B01000111,B01000111,B01000111,B00000111,B01000100,B01000100,B01000100,B00000001,B01000001,B01000100,B01000100,B00000010,
    B00000010,B00000010,B00000010,B00000010,B00000010,B00000010,B00000010,B00000010,B00000010,B00000010,B00000010,B00000010,B00000010,B00000010,B00000010,B00000010,B00000010,B00000010,B00000010,B00000010,B00000010,B00000010,B00000010,B00000010,B00000010,B00000010,B00000010,B00000010,B00000010,B00010111,B00010111,B00000010,
};
static const byte PROGMEM pixels1[12*8*32] = 
{
    B01111100,B11111111,B11111111,B11111111,B11111111,B11111111,B11111111,B11111111,B11111111,B11111111,B11111111,B11111111,B11111111,B11111111,B11111111,B11111111,B11111111,B11111111,B11111111,B11111111,B11111111,B11111111,B11111111,B11111111,B11111111,B11111111,B11111111,B11111111,B11111111,B11111111,B11111111,B00111110,
    B10000010,B10101010,B10101010,B10101010,B10101010,B10101010,B10101010,B10101010,B10101010,B10101010,B10101010,B10101010,B10101010,B10101010,B10101010,B10101010,B10101010,B10101010,B10101010,B10101010,B10101010,B10101010,B10101010,B10101010,B10101010,B10101010,B10101010,B10101010,B10101010,B10101010,B10101010,B01000001,
    B10010110,B01010101,B01010101,B01010101,B01010101,B01010101,B01010101,B01010101,B01010101,B01010101,B01010101,B01010101,B01010101,B01010101,B01010101,B01010101,B01010101,B01010101,B01010101,B01010101,B01010101,B01010101,B01010101,B01010101,B01010101,B01010101,B01010101,B01010101,B01010101,B01010101,B01010101,B01001011,
    B10101110,B00000000,B00000000,B00000000,B00000000,B00000000,B00000000,B00000000,B00000000,B00000000,B00000000,B00000000,B00000000,B00000000,B00000000,B00000000,B00000000,B00000000,B00000000,B00000000,B00000000,B00000000,B00000000,B00000000,B00000000,B00000000,B00000000,B00000000,B00000000,B00000000,B00000000,B01010111,
    B10010110,B01010101,B01010101,B01010101,B01010101,B01010101,B01010101,B01010101,B01010101,B01010101,B01010101,B01010101,B01010101,B01010101,B01010101,B01010101,B01010101,B01010101,B01010101,B01010101,B01010101,B01010101,B01010101,B01010101,B01010101,B01010101,B01010101,B01010101,B01010101,B01010101,B01010101,B01001011,
    B10111110,B10101010,B10101010,B10101010,B10101010,B10101010,B10101010,B10101010,B10101010,B10101010,B10101010,B10101010,B10101010,B10101010,B10101010,B10101010,B10101010,B10101010,B10101010,B10101010,B10101010,B10101010,B10101010,B10101010,B10101010,B10101010,B10101010,B10101010,B10101010,B10101010,B10101010,B01011111,
    B01111100,B11111111,B11111111,B11111111,B11111111,B11111111,B11111111,B11111111,B11111111,B11111111,B11111111,B11111111,B11111111,B11111111,B11111111,B11111111,B11111111,B11111111,B11111111,B11111111,B11111111,B11111111,B11111111,B11111111,B11111111,B11111111,B11111111,B11111111,B11111111,B11111111,B11111111,B00111110,
    B00000001,B11111111,B11111111,B11111111,B11111111,B11111111,B11111111,B11111111,B11111111,B11111111,B11111111,B11111111,B11111111,B11111111,B11111111,B11111111,B11111111,B11111111,B11111111,B11111111,B11111111,B11111111,B11111111,B11111111,B11111111,B11111111,B11111111,B11111111,B11111111,B11111111,B11111111,B10000000,
    B10101011,B00000000,B00000000,B00000000,B00000000,B00000000,B00000000,B00000000,B00000000,B00000000,B00000000,B00000000,B00000000,B00000000,B00000000,B00000000,B11111111,B00000000,B00000000,B11111111,B00000000,B00000000,B00000000,B00000000,B00000000,B00000000,B11111111,B00000000,B00000000,B00000000,B00000000,B10101011,
    B11000111,B00000000,B00000000,B00000000,B00000000,B00000000,B00000000,B00000000,B00000000,B00000000,B00000000,B00000000,B00000000,B00000000,B00000000,B00000000,B11111111,B00000000,B00000000,B11111111,B00000000,B00000000,B00000000,B00000000,B00000000,B00000000,B11111111,B00000000,B00000000,B00000000,B00000000,B11000111,
    B10101011,B00000000,B00011000,B00000000,B00000000,B00000000,B00000000,B00000000,B00000000,B00000000,B00000000,B00000000,B00000000,B00000000,B00000000,B00000000,B11111111,B00000000,B00000000,B11111111,B00000000,B00000000,B00000000,B00000000,B00000000,B00000000,B11111111,B00000000,B00000000,B00000000,B00000000,B10101011,
    B11000111,B00000000,B00011000,B00000000,B00000000,B00000000,B00000000,B00000000,B00000000,B00000000,B00000000,B00000000,B00000000,B00000000,B00000000,B00000000,B11111111,B00000000,B00000000,B11111111,B00000000,B00000000,B00111111,B11111100,B00000000,B01000000,B11111111,B00000001,B11111111,B11111111,B11000000,B11000111,
    B10101011,B00111000,B00001000,B00000000,B00000000,B00000000,B00000000,B00000000,B00000000,B00000000,B00000000,B00000000,B00000000,B00000000,B00000000,B00000000,B11111111,B00000000,B00000000,B11111111,B00000000,B00000000,B01111111,B11111000,B00000000,B11100000,B11111111,B00001100,B11111111,B11111111,B11110000,B10101011,
    B11000111,B00111000,B00000000,B00000000,B00000000,B00000000,B00000000,B00000000,B00000000,B00000000,B00000000,B00000000,B00000000,B00000000,B00000000,B00000000,B11111111,B00000000,B00000000,B11111111,B00000000,B00000011,B01111111,B11110000,B00000011,B11100000,B11111111,B00000111,B11111111,B11111111,B11110000,B11000111,
    B10101011,B00010001,B11000000,B00000000,B00000000,B00000000,B00000000,B00000000,B00000000,B00000000,B00000000,B00000000,B00000000,B00000000,B00000000,B00000000,B11111111,B00000000,B00000000,B11111111,B00000000,B00000111,B00111111,B11000000,B00000111,B10000000,B11111111,B00000011,B11111111,B11111111,B11111000,B10101011,
    B11000111,B00000011,B11100011,B11111111,B11101100,B00000011,B10111111,B11111110,B00001111,B10000000,B00111111,B11111110,B00011111,B11100011,B11111111,B11101100,B11111111,B10111111,B11111000,B11111111,B00110000,B00000111,B10001000,B00000000,B00000011,B00000000,B11111111,B00000000,B11111111,B11111111,B11111000,B11000111,
    B10101011,B00000011,B11110001,B10011100,B11000111,B00000011,B10011100,B00001100,B00000111,B00000000,B00011100,B00001100,B00111000,B01110001,B11000000,B11000111,B00000001,B10011100,B00011100,B00000000,B10110000,B00111111,B00000000,B00000000,B00000000,B11111111,B00000000,B00100000,B00111111,B11111111,B11111000,B10101011,
    B11000111,B00010011,B11111000,B10011100,B10000111,B00000011,B10011100,B10001000,B00000111,B00000000,B00011100,B10001000,B01110000,B00111001,B11001000,B10000111,B11000011,B10011100,B00001110,B00000001,B11000000,B11111000,B00000000,B00000000,B00000000,B11111111,B00010000,B01000000,B00001111,B11111111,B11111100,B11000111,
    B10101011,B00011011,B11100000,B00011100,B00000111,B11111111,B10011111,B10000000,B00000111,B00000000,B00111111,B10000000,B01110000,B00000011,B11111000,B00000111,B11110011,B10011100,B00001110,B00000111,B11000001,B11100000,B00000000,B00000000,B00000000,B11111111,B00010000,B11000000,B00000111,B11111111,B11111100,B10101011,
    B11000111,B00011001,B11000000,B00011100,B00000111,B00000011,B10011100,B10000000,B00000111,B00000000,B00011100,B10000000,B01110000,B00000001,B11001000,B00000111,B00111111,B10011100,B00001110,B00000111,B11110011,B11000000,B00000000,B00000000,B00000000,B11111111,B00011001,B10000000,B00000111,B11111111,B11111100,B11000111,
    B10101011,B00011100,B10000100,B00011100,B00000111,B00000011,B10011100,B00000000,B00000111,B00000000,B00011100,B00000000,B01110011,B11111001,B11000000,B00000111,B00001111,B10011100,B00001110,B00001111,B11100111,B10001110,B00000000,B00000000,B00000000,B11111111,B00011001,B01111100,B00000111,B11111111,B11111100,B10101011,
    B11000111,B00111110,B00011100,B00011100,B00000111,B00000011,B10011100,B00000000,B00000111,B00000000,B00011100,B00000000,B01110001,B10111001,B11000000,B00000111,B00000011,B10011100,B00001110,B00000011,B11101111,B10011111,B00001110,B00000000,B00000000,B11111111,B00001010,B11111110,B00000011,B11111111,B11111100,B11000111,
    B10101011,B00111111,B00111100,B00011100,B00000111,B00000011,B10011100,B00000000,B00000111,B00000000,B00011100,B00000000,B01110000,B10111001,B11000000,B00000111,B00000011,B10011100,B00001110,B00000000,B11011111,B00111110,B00000001,B11000011,B11100000,B11111111,B00001011,B11111111,B00000001,B11111111,B11111100,B10101011,
    B11000111,B00111110,B01111110,B00011100,B00000111,B00000011,B10011100,B00001000,B00000111,B00000010,B00011100,B00001000,B01110000,B00111001,B11000000,B10000111,B00000011,B10011100,B00001110,B00000000,B01011111,B00111110,B00000000,B01110111,B11111000,B11111111,B00011111,B11111111,B00000000,B11111111,B11111100,B11000111,
    B10101011,B00011110,B01111100,B00011100,B00000110,B00000001,B10011100,B00001100,B00000111,B00000011,B00011100,B00001100,B00111000,B01110001,B11000000,B11000110,B00000001,B10011100,B00011100,B00000111,B00111111,B01111100,B00000000,B00010111,B11111111,B00000111,B11100000,B11111111,B10000000,B11111111,B11111100,B10101011,
    B11000111,B00011110,B11111000,B00111110,B00000100,B00000000,B10111111,B11111110,B00001111,B11111111,B10111111,B11111110,B00011111,B11100011,B11111111,B11100100,B00000000,B10111111,B11111000,B00001111,B10111110,B01110001,B00000000,B00000111,B10111101,B00000011,B00011100,B11111111,B10000000,B11111111,B11111100,B11000111,
    B10101011,B00111110,B11111100,B00000000,B00000000,B00000000,B00000000,B00000000,B00000000,B00000000,B00000000,B00000000,B00000000,B00000000,B00000000,B00000000,B00000000,B00000000,B00000000,B00011111,B11011110,B01111111,B00000000,B11011011,B10111110,B00010001,B10000011,B11111111,B11000000,B01111111,B11111100,B10101011,
    B11000111,B00111110,B11111110,B00000000,B00000000,B00000000,B00000000,B00000000,B00000000,B00000000,B00000111,B10011111,B11000000,B00000000,B00000000,B00000000,B00000000,B00000000,B00000000,B00011111,B11011110,B11111111,B00000011,B00111001,B11111111,B10011011,B11000000,B00111111,B11000000,B01111111,B11111100,B11000111,
    B10101011,B00111110,B11111111,B00000000,B00000001,B11111111,B11111111,B11111111,B11111111,B11111111,B10001100,B11001100,B10001111,B11111111,B11111111,B11111111,B11111111,B00000000,B00000000,B00111111,B11011110,B11111111,B00000100,B01110001,B10110111,B11011111,B11100000,B11011111,B11100000,B01111111,B11111100,B10101011,
    B11000111,B00011111,B01111110,B00000000,B00000000,B00000000,B00000000,B00000000,B00000000,B00000000,B00001100,B11001100,B00000000,B00000000,B00000000,B00000000,B00000000,B00000000,B00000000,B00111111,B11111110,B11111111,B00000000,B11101000,B10010110,B01100011,B00010000,B11101111,B11100000,B01111111,B11111100,B11000111,
    B10101011,B00111111,B01111111,B00000000,B01000001,B11111111,B11111111,B11111111,B11111111,B11111010,B00001100,B11011111,B00001101,B11111111,B11111111,B11111111,B11110000,B00000000,B00000000,B00111111,B11111110,B11111111,B00000000,B11010000,B10011011,B00010001,B11000000,B11110111,B11100000,B01111111,B11111000,B10101011,
    B11000111,B00111111,B01111110,B00000000,B10100000,B10000000,B00000000,B00000000,B00000000,B00010101,B00001100,B11001100,B00010010,B10000000,B00000000,B00000000,B00100000,B00000000,B00000001,B00111111,B11111111,B01111111,B00000001,B11010000,B10001001,B00000000,B01110000,B11110111,B11110000,B01111111,B11111100,B11000111,
    B10101011,B00011111,B10111111,B10001000,B11110000,B01000000,B00000000,B00000000,B00000000,B00101000,B10001100,B11001100,B00100001,B01000000,B00000000,B00000000,B01000000,B11111111,B00000001,B00011111,B11111111,B01111110,B00000001,B10100010,B00100000,B00000000,B11111111,B11111011,B11110000,B01111110,B00111100,B10101011,
    B11000111,B00111111,B11111111,B00011100,B11111000,B00101111,B11111111,B11111111,B11111111,B01010001,B01001100,B11001100,B01000110,B10101111,B11111111,B11111110,B10000000,B11111111,B00000001,B10011111,B11111111,B10111110,B00000011,B10100111,B00111000,B00000000,B11111111,B11111011,B11110000,B01110000,B11111100,B11000111,
    B10101011,B00111111,B11111111,B00111110,B01111100,B00010111,B11111111,B11111111,B11111110,B10100011,B10100111,B10001100,B10001111,B01010111,B11111111,B11111101,B00000000,B11111111,B00000011,B10011111,B11111111,B11111110,B00000011,B10100111,B10111100,B10000000,B11111111,B11111101,B11110000,B00100011,B11111100,B10101011,
    B11000111,B00111111,B11111110,B01111111,B00111100,B00001011,B11111111,B11111111,B11111101,B01000111,B11010000,B00000001,B00011111,B10101011,B11111111,B11111010,B00000000,B11111111,B00000011,B11001111,B11101111,B11111110,B00000011,B10000111,B10011110,B11000000,B11111111,B11111101,B11111000,B00000111,B11111100,B11000111,
    B10101011,B00111111,B11111100,B11111111,B11000010,B00000101,B11111111,B11111111,B11111010,B01001111,B11101000,B00000010,B00111111,B01000101,B11111111,B11110100,B00000000,B11111111,B00000011,B11101111,B11100111,B11111100,B00000011,B10000111,B11011111,B11100000,B11110101,B11101101,B11111000,B00001111,B11111000,B10101011,
    B11000111,B00111111,B11110011,B11111111,B11110111,B00000010,B11111111,B11111111,B11110100,B00101111,B11110100,B00000100,B01111110,B10000100,B11111111,B11110100,B00000000,B11111111,B00000001,B11110111,B11110000,B11111000,B00000011,B10001111,B11111110,B11110000,B11111010,B11110110,B11011000,B00001111,B11111100,B11000111,
    B10101011,B00111111,B11111111,B11111111,B11110011,B00000001,B00000001,B11111000,B00001000,B00010111,B11111010,B00001000,B11111101,B00001000,B11111111,B11111010,B00000000,B11111111,B00000000,B11111111,B11111100,B00000000,B00000011,B10001100,B11111110,B01111000,B11111100,B11110010,B11011100,B00011111,B11111100,B10101011,
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
void loop()
{
    int y;

    // generate signals for a whole frame
    for (y=0; y<96; y++)
    {
        sendline(attributes+((y/8)*32), pixels1+(y*32));
    }
    for (y=96; y<192; y++)
    {
        sendline(attributes+((y/8)*32), pixels2+((y-96)*32));
        if (y==190) { sendio(7); }   // set grey background during last image line
        if (y==191) { sendio(0); }   // set black background after the last image line
    }
    for (y=192; y<200; y++) 
    {   
        blankline();  
        if (y==192) { sendio(2); }   // red color for line 193
        if (y==193) { sendio(3); }   // purple color for line 193
        if (y==194) { sendio(1); }   // blue color for line 193
        if (y==195) { sendio(0); }   // black for line 195 onwards
    }
    
    hsync();   // line 200 has a middle transition to yellow
    sendio(6);
    hsync();   // line 201 has a middle transition to black
    sendio(0);
    
    for (y=202; y<312; y++) { blankline(); }   
    
    illegalio(7);  // try illegal sequence to set background color gray
}

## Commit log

2020-02-29 Start layouting
    [board-2020-02-29-15-14-13.sch, board.kicad_pcb, board.sch]
2020-03-02 Ongoing design
    Squeezing all necessary electronics onto a 3.3mm x 5.1mm board
    [board.kicad_pcb, board.sch]
2020-03-03 Layout complete (version 1)
    [board.kicad_pcb, board.sch]
2020-04-28 Pin assignment list
2020-05-16 Redesign mode jumpers. Minor fixes in silk screen.
    [board.kicad_pcb, board.sch]
2020-05-21 Modify PCB for easier assembly
    [board.kicad_pcb]
2020-05-22 Simplified border color generation. Fix up test program.
    [signalgenerator.ino]
2021-01-27 Add BOM
    [ZXcompBOM.ods]
2023-10-15 Generate auxilary 14MHz clock in case it is needed by a faulty ULA
